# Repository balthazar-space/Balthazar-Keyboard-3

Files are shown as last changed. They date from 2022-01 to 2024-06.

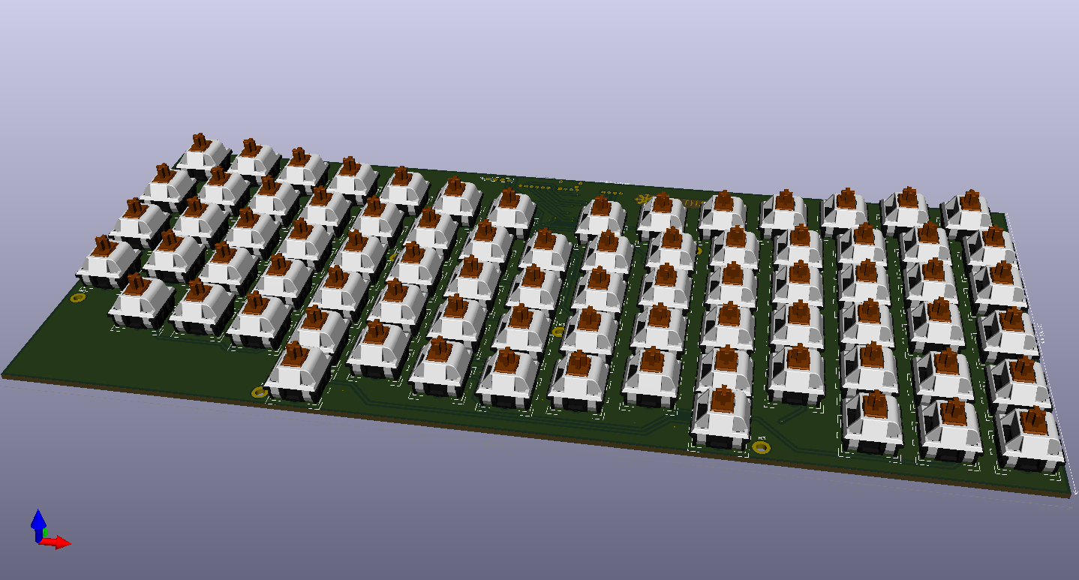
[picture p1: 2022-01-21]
images/BalthazarKeyboard3-keycaps02.png

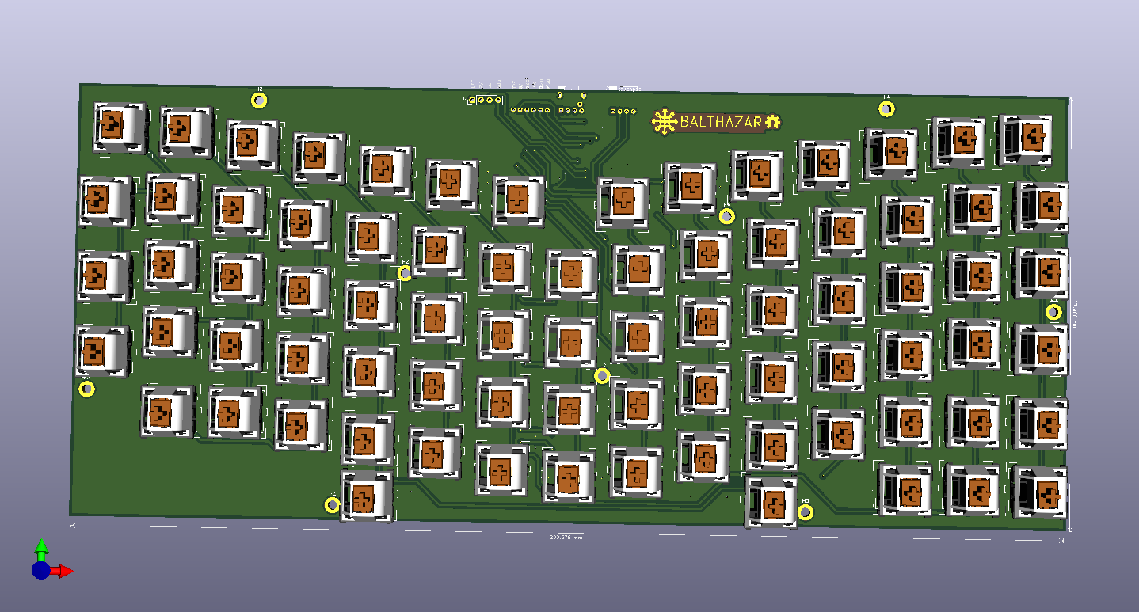
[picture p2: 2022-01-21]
images/BalthazarKeyboard3-keycaps01.png

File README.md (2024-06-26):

# Balthazar

Open-hardware laptop computer modules description and concept.

These are electronic schematic modules as presented at https://balthazar.space/wiki/Balthazar with the main aim for team access. See the [main repository](https://github.com/balthazar-space/balthazar) for other designs.

# Balthazar Keyboard 3

Balthazar keyboard with keycaps.

Computer Keyboard version 3 system built around an 8-bit Atmel ATmega 32u4 microcontroller. A normal ISO keyboard layout is used. The PCB design is for Cherry keycaps. Schematics layout and connections are a bit simplified over version 2.

An option is given for the onboard microcontroller to handle also the control for PSU board, the OLED module, bluetooth module and the ps/2 touchpad module. For this I2C, SPI and PS/2 serial connections are exposed - and are optional. The QMK code has not been updated with all these options yet. 

QMK code in QMK folder reflects the simplifications of this version - basically just the more straightforward selection of row pins of the microcontroller.

Keyboard pcb has dimensions predefined by the LCD's dimensions of 13.3 inch diagonal: 290mm width. The width is the most determining factor for the keys raster which is about 17mm – instead of the regular 19mm.

The keys have some ergonomic solution that gives some additional design touch. The keycaps here are positioned vertically which is not the best solution (keycaps orientation should follow the wave of the design...). 

KiCad 5.1.5 files are uploaded here as well as the drawings pictures and firmware code.

### OLED & boot sequence

A 128x32 SSD130 64x128 display connected via i2c is used.
When starting up, you are asked to enter a password. If it's not set up yet, a new one can be entered.
After successful authentication, a boot menu is presented.

**_beware:_** The password is saved plaintext in the microcontroller's EEPROM. It can be extracted with proper equipment and can easily be overwritten on the currently used ATmega32u4.

## License

All resources except the keyboard firmware - which is licensed with with GPLv3 or later - licensed under the CERN Open Hardware Licence CERN-OHL W V.2.0

Version 2.0 of the CERN-OHL introduces three variants of the licence – strongly (S) reciprocal, weakly (W) reciprocal and permissive (P) – which aim to address specific constraints caused by different collaboration models currently used in open-hardware projects. 

The first two variants mean that if any product is made using an open hardware design, the design of that product, including any improvements or modifications, should be made available under the same licence as that of the original product. Permissive licences do not impose this condition.

See the [LICENSE.md](./LICENSE.md) file for more information.

## Funding

This project is funded through the [NGI Zero Entrust Fund](https://nlnet.nl/entrust), a fund
established by [NLnet](https://nlnet.nl) with financial support from the European Commission's
[Next Generation Internet](https://ngi.eu) program. Learn more on the [NLnet project page](https://nlnet.nl/project/Balthazar-Casing/).

[NLNet foundation logo](https://nlnet.nl)
[NGI0 Entrust Logo](https://nlnet.nl/entrust)

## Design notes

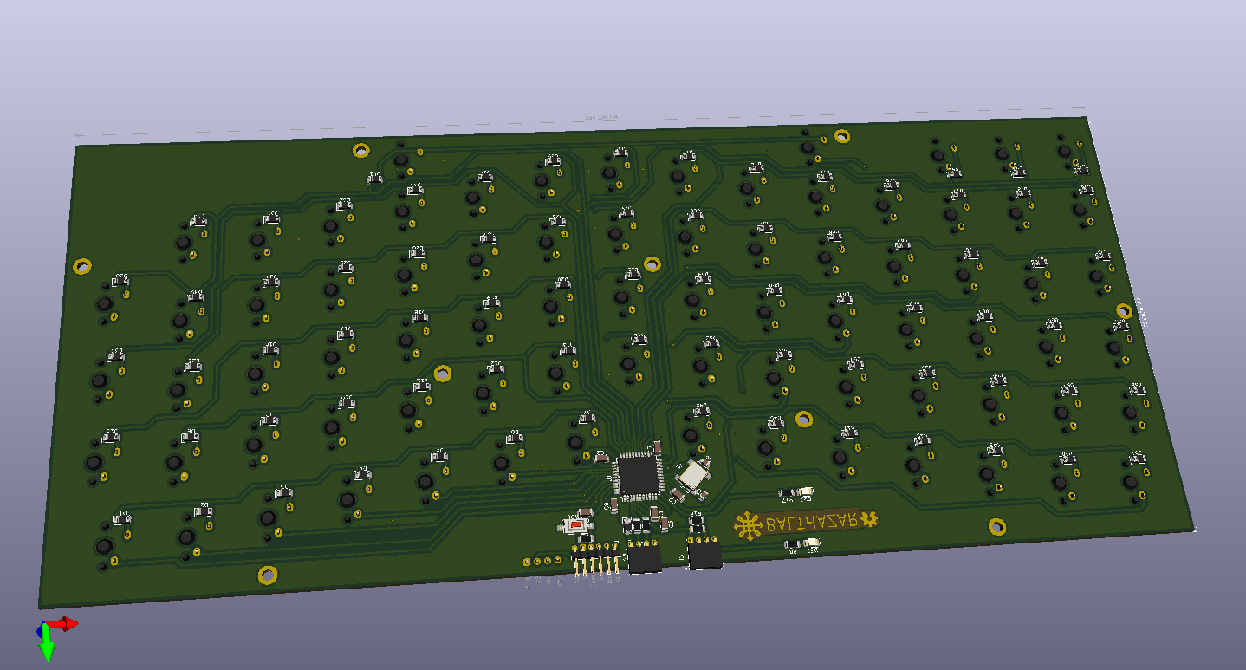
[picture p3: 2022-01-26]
images/BalthazarKeyboard3-keycaps05.png

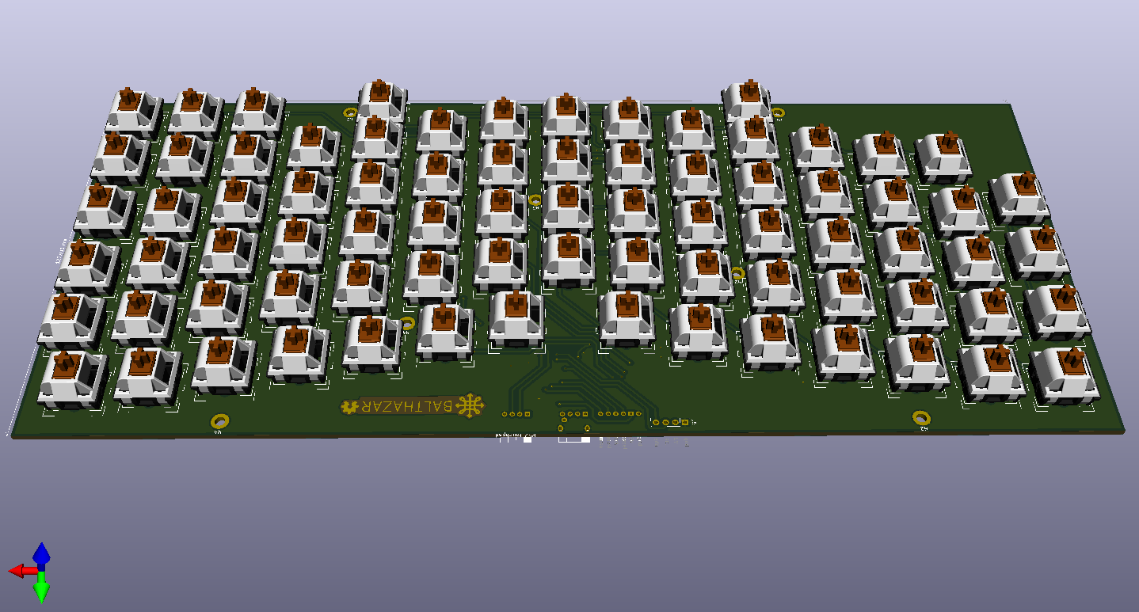
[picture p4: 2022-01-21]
images/BalthazarKeyboard3-keycaps04.png

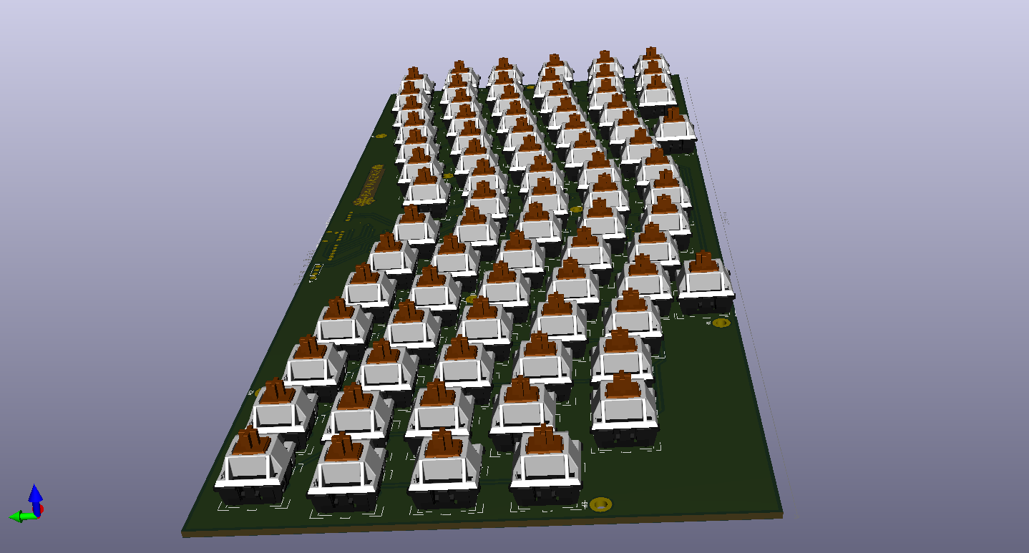
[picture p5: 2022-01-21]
images/BalthazarKeyboard3-keycaps03.png

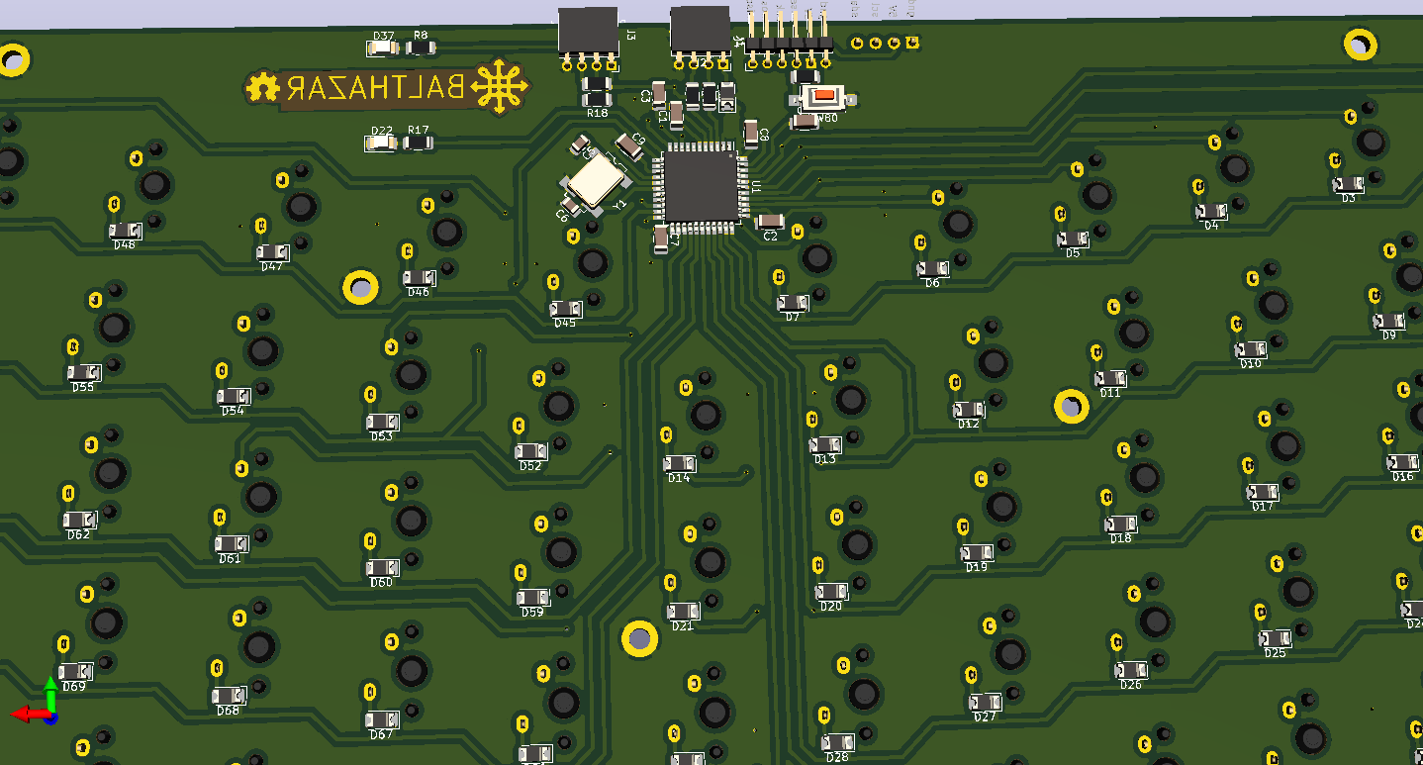
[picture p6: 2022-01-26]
images/BalthazarKeyboard3-keycaps06.png

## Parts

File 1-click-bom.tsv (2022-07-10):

References | Qty | Description | Manufacturer | MPN | Manufacturer | MPN | Manufacturer | MPN | Manufacturer | MPN | Manufacturer | MPN | Manufacturer | MPN | Digikey | Mouser | RS | Newark | Farnell | LCSC | JLC Assembly
C1 | 1 | Multilayer Ceramic Capacitors MLCC - SMD/SMT WCAP-CSGP 1uF 1206 10% 16V MLCC | Wurth Elektronik | 885012208036 | AVX | 885012208036 | AVX | TAJA105K035RNJ |  | TAJA105K035RNJ |  |  |  |  | 732-7692-6-ND | 581TAJA105K035R | 1360144 |  | 1135061
C2 | 1 | Multilayer Ceramic Capacitors MLCC - SMD/SMT 25 VDC 10uF X5R 1206 | KEMET | C1206C106M3PAC7210 |  | C1206C106M3PAC7210 |  |  |  |  |  |  |  |  |  | 80C1206C106M3PACLR |  |  | 3511493
C5, C6 | 2 | Multilayer Ceramic Capacitors MLCC - SMD/SMT 16V 22pF C0G 0805 5% | KYOCERA AVX | 885012007012 | Wurth Elektronik | 885012007012 |  |  |  |  |  |  |  |  | 732-7816-1-ND | 710885012007012 | 1814089 |  | 2812134
D1, D2, D3, D4, D5, D6, D7, D8, D9, D10, D11, D12, D13, D14, D15, D16, D17, D18, D19, D20, D21, D23, D24, D25, D26, D27, D28, D29, D30, D31, D32, D33, D34, D35, D36, D38, D39, D40, D41, D42, D43, D44, D45, D46, D47, D48, D49, D50, D51, D52, D53, D54, D55, D56, D57, D58, D59, D60, D61, D62, D63, D64, D65, D66, D67, D68, D69, D70, D71, D72, D73, D74, D75, D76, D77, D78, D79 | 77 | Diodes - General Purpose, Power, Switching 75V, 0.15A, Switching Diode & Array | Taiwan Semiconductor | TS4148 RXG |  | TS4148 RXG |  |  |  |  |  |  |  |  |  | 821TS4148RXG | 6526003 |  | 2708388
C3, C4, C7, C8, C9 | 5 | Multilayer Ceramic Capacitors MLCC - SMD/SMT 50V 0.1uF X7R 1206 20% | KEMET | C1206C104M5RACTU |  | C1206C104M5RACTU |  |  |  |  |  |  |  |  | 399-C1206C104M5RAC7800DKR-ND | 80C1206C104M5R | 2053277P |  | 2581103 |  | ,,,,,,,,,,,,,,,,,,,,,,,,,,,,,,,,,,,,,,,,,,,,,,,,,,,,,,,,,,,,,,,,,,,,,,,,,,,,
R7, R18, R19 | 3 | Thick Film Resistors - SMD 10 kOhms 250 mW 1206 5% | Vishay | RC1206JR-0710KL | Panasonic | CRCW120610K0FKEA | Yageo | ERJ-8ENF1002V | Yageo | RC1206FR-0710KL | Yageo | RC1206JR-0710KL |  | RC1206JR-0710KL | 311-10.0KFRCT-ND | 603RC1206FR0710KL | 1995772P |  | 9241000
R3, R4 | 2 | Thick Film Resistors - SMD 22ohms 1% 100ppm | Vishay Dale | RCC120622R0FKEA |  | RCC120622R0FKEA |  |  |  |  |  |  |  |  | 541-RCC120622R0FKEADKR-ND | 71RCC120622R0FKEA |  |  | 3755550
R8, R17 | 2 | Thick Film Resistors - SMD 200 Ohms 250 mW 1206 1% | Yageo | RC1206FR-07200RL |  | RC1206FR-07200RL |  |  |  |  |  |  |  |  | 311-200FRDKR-ND | 603RC1206FR07200RL |  |  | 3496175
L1 | 1 | Fixed Inductors 1.5uH 10% | Cooper Bussmann | ILSB1206ER1R5K | Vishay Dale | MFBW1V3216-500-R | Vishay Dale | ILSB1206ER1R5K | Cooper Bussmann | ILSB1206ER1R5K |  | MFBW1V3216-500-R |  |  | ILSB1206ER1R5K-ND | 704MFBW1V3216500R
U1 | 1 | 8-bit Microcontrollers - MCU USB 32K Flash 16 MHz | Microchip | ATMEGA32U4-AUR |  | ATMEGA32U4-AUR |  |  |  |  |  |  |  |  | ATMEGA32U4-AURDKR-ND | 556ATMEGA32U4AUR | 1772992P |  | 2443182RL
Y1 | 1 | Standard Clock Oscillators SG-8018CB 16.0000M-TJHPA3: MHZ OSC 1.8V~3.3V +/-50PPM -40~105C O/E 250TR | Epson | SG-8018CB 16.0000M-TJHPA3 |  | SG-8018CB 16.0000M-TJHPA3 |  |  |  |  |  |  |  |  |  | 732CB16MTJHPA3
D22, D37 | 2 | Standard LEDs - SMD Green | Stanley Electric | RPG1102W-660-TR |  | RPG1102W-660-TR |  |  |  |  |  |  |  |  | 404-1232-1-ND | 327RPG1102W660TR
SW1-SW79 | 78 | Pushbutton Switches Silver stem, RGB | Cherry | MX1A-51NA |  | MX1A-51NA |  | MX1A-11NW |  |  |  |  |  |  | MX1A-51NA-ND | 540MX1A11NW
SW80 | 1 | Tactile Switches SPST 0.05A 12V 250gf | C&K Components | RS282G05A3SMRT |  | RS282G05A3SMRT |  |  |  |  |  |  |  |  | CKN10384CT-ND | 611RS282G05A3SMRT | 1769434 |  | 3263270
J2 | 1 | USB Connectors Micro B Skt, Top Mount-SMT | Global Connector Technology | USB3505-30-A |  | USB3505-30-A |  |  |  |  |  |  |  |  | 2073-USB3505-30-ATR-ND | 640USB350530A
KEYCAPS | 78 | KEYCAPS CHERRY MX |  | 474-PRT-15305 |  | PRT-15305 |  |  |  |  |  |  |  |  |  | 474PRT15305
J1, J3 | 2 | PinSocket_1x04_P2.00mm_Horizontal |  | SQT-104-01-F-S-RA |  |  |  |  |  |  |  |  |  |  |  | 200SQT10401FSRA
J4 | 1 | PinHeader_1x06_P2.00mm_Horizontal |  | 35363-0660 |  |  |  |  |  |  |  |  |  |  |  | 538353630660
J5 | 1 | PinHeader_1x04_P2.54mm_Vertical |  | M20-9990446 |  |  |  |  |  |  |  |  |  |  |  | 855M209990446

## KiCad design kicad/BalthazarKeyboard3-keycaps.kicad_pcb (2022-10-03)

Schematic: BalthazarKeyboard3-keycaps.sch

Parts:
C1: 1uF; C_1206_3216Metric
C2: 10uF; C_1206_3216Metric
C3, C4, C7, C8, C9: 0.1uF; C_1206_3216Metric
C5, C6: 22pF; C_0805_2012Metric
D1, D2, D3, D4, D5, D6, D7, D8, D9, D10, D11, D12, D13, D14, D15, D16, D17, D18, D19, D20, D21, D23, D24, D25, D26, D27, D28, D29, D30, D31, D32, D33, D34, D35, D36, D38, D39, D40, D41, D42, D43, D44, D45, D46, D47, D48, D49, D50, D51, D52, D53, D54, D55, D56, D57, D58, D59, D60, D61, D62, D63, D64, D65, D66, D67, D68, D69, D70, D71, D72, D73, D74, D75, D76, D77, D78, D79: D; D_1206_3216Metric
D22, D37: LED_Small; LED_1206_3216Metric
H1, H2, H3, H4: MountingHole_Pad; MountingHole_2.7mm_M2.5_DIN965_Pad
J1: USB; PinSocket_1x04_P2.00mm_Horizontal
J2: USB_B_Micro; USB_Micro-B_Molex-Balthazar
J3: PS2 touchpad; PinSocket_1x04_P2.00mm_Horizontal
J4: ISP; PinHeader_1x06_P2.00mm_Horizontal
J5: I2C; PinHeader_1x04_P2.54mm_Vertical
L1: L_Core_Ferrite_Small; D_1206_3216Metric
R3, R4: 22; R_1206_3216Metric
R7, R18, R19: 10K; R_1206_3216Metric
R8, R17: 200; R_1206_3216Metric
SW1: ESC; CherryMX_RGB_SpeedSilver
SW2: F1; CherryMX_RGB_SpeedSilver
SW3: F2; CherryMX_RGB_SpeedSilver
SW4: F3; CherryMX_RGB_SpeedSilver
SW5: F4; CherryMX_RGB_SpeedSilver
SW6: F5; CherryMX_RGB_SpeedSilver
SW7: F6; CherryMX_RGB_SpeedSilver
SW8: GRAVE; CherryMX_RGB_SpeedSilver
SW9: 1; CherryMX_RGB_SpeedSilver
SW10: 2; CherryMX_RGB_SpeedSilver
SW11: 3; CherryMX_RGB_SpeedSilver
SW12: 4; CherryMX_RGB_SpeedSilver
SW13: 5; CherryMX_RGB_SpeedSilver
SW14: 6; CherryMX_RGB_SpeedSilver
SW15: TAB; CherryMX_RGB_SpeedSilver
SW16: Q; CherryMX_RGB_SpeedSilver
SW17: W; CherryMX_RGB_SpeedSilver
SW18: E; CherryMX_RGB_SpeedSilver
SW19: R; CherryMX_RGB_SpeedSilver
SW20: T; CherryMX_RGB_SpeedSilver
SW21: Y; CherryMX_RGB_SpeedSilver
SW22: CAPS; CherryMX_RGB_SpeedSilver
SW23: A; CherryMX_RGB_SpeedSilver
SW24: S; CherryMX_RGB_SpeedSilver
SW25: D; CherryMX_RGB_SpeedSilver
SW26: F; CherryMX_RGB_SpeedSilver
SW27: G; CherryMX_RGB_SpeedSilver
SW28: H; CherryMX_RGB_SpeedSilver
SW29: SHIFT; CherryMX_RGB_SpeedSilver
SW30: NUBS; CherryMX_RGB_SpeedSilver
SW31: Z; CherryMX_RGB_SpeedSilver
SW32: X; CherryMX_RGB_SpeedSilver
SW33: C; CherryMX_RGB_SpeedSilver
SW34: V; CherryMX_RGB_SpeedSilver
SW35: B; CherryMX_RGB_SpeedSilver
SW36: CTRL; CherryMX_RGB_SpeedSilver
SW37: ALT; CherryMX_RGB_SpeedSilver
SW38: GUI; CherryMX_RGB_SpeedSilver
SW39, SW40: SPACE; CherryMX_RGB_SpeedSilver
SW42: LEFT; CherryMX_RGB_SpeedSilver
SW43: DOWN; CherryMX_RGB_SpeedSilver
SW44: RIGHT; CherryMX_RGB_SpeedSilver
SW45: F7; CherryMX_RGB_SpeedSilver
SW46: F8; CherryMX_RGB_SpeedSilver
SW47: F9; CherryMX_RGB_SpeedSilver
SW48: F10; CherryMX_RGB_SpeedSilver
SW49: F11; CherryMX_RGB_SpeedSilver
SW50: F12; CherryMX_RGB_SpeedSilver
SW51: PRTSCR; CherryMX_RGB_SpeedSilver
SW52: 7; CherryMX_RGB_SpeedSilver
SW53: 8; CherryMX_RGB_SpeedSilver
SW54: 9; CherryMX_RGB_SpeedSilver
SW55: 0; CherryMX_RGB_SpeedSilver
SW56: MINUS; CherryMX_RGB_SpeedSilver
SW57: EQUAL; CherryMX_RGB_SpeedSilver
SW58: DELETE; CherryMX_RGB_SpeedSilver
SW59: U; CherryMX_RGB_SpeedSilver
SW60: I; CherryMX_RGB_SpeedSilver
SW61: O; CherryMX_RGB_SpeedSilver
SW62: P; CherryMX_RGB_SpeedSilver
SW63: LBRC; CherryMX_RGB_SpeedSilver
SW64: RBRC; CherryMX_RGB_SpeedSilver
SW65: BACKSPACE; CherryMX_RGB_SpeedSilver
SW66: J; CherryMX_RGB_SpeedSilver
SW67: K; CherryMX_RGB_SpeedSilver
SW68: L; CherryMX_RGB_SpeedSilver
SW69: SCLN; CherryMX_RGB_SpeedSilver
SW70: QUOTE; CherryMX_RGB_SpeedSilver
SW71: NUHS; CherryMX_RGB_SpeedSilver
SW72: ENTER; CherryMX_RGB_SpeedSilver
SW73: N; CherryMX_RGB_SpeedSilver
SW74: M; CherryMX_RGB_SpeedSilver
SW75: COMMA; CherryMX_RGB_SpeedSilver
SW76: DOT; CherryMX_RGB_SpeedSilver
SW77: SLASH; CherryMX_RGB_SpeedSilver
SW78: UP; CherryMX_RGB_SpeedSilver
SW79: ALTGR; CherryMX_RGB_SpeedSilver
SW80: SW_Push; SW_SPST_CK_RS282G05A3
U1: ATmega32U4_Balthazar; TQFP-44_10x10mm_P0.8mm
U3: Arduino_ProMicro
Y1: Crystal_16M; Crystal_SMD_SeikoEpson_MC306-4Pin_8.0x3.2mm_HandSoldering

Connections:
GND: C1.2, C2.1, C3.1, C4.2, C5.2, C6.2, C7.1, C8.1, C9.1, D22.1 (K), D37.1 (K), H1.1, H2.1, H3.1, H4.1, J1.4, J2.5 (GND), J2.6 (Shield), J3.4, J4.6, J5.1, SW80.1, U1.5 (UGND), U1.15 (GND), U1.23 (GND), U1.35 (GND), U1.43 (GND), Y1.2, Y1.4; also elsewhere on the board
unnamed: C1.1, U1.6 (UCAP)
unnamed: C4.1, U1.42 (AREF)
unnamed: C5.1, U1.16 (XTAL2), Y1.1
unnamed: C6.1, U1.17 (XTAL1), Y1.3
unnamed: D1.2 (A), SW1.2
unnamed: D2.2 (A), SW2.2
unnamed: D3.2 (A), SW3.2
unnamed: D4.2 (A), SW4.2
unnamed: D5.2 (A), SW5.2
unnamed: D6.2 (A), SW6.2
unnamed: D7.2 (A), SW7.2
unnamed: D8.2 (A), SW8.2
unnamed: D9.2 (A), SW9.2
unnamed: D10.2 (A), SW10.2
unnamed: D11.2 (A), SW11.2
unnamed: D12.2 (A), SW12.2
unnamed: D13.2 (A), SW13.2
unnamed: D14.2 (A), SW14.2
unnamed: D15.2 (A), SW15.2
unnamed: D16.2 (A), SW16.2
unnamed: D17.2 (A), SW17.2
unnamed: D18.2 (A), SW18.2
unnamed: D19.2 (A), SW19.2
unnamed: D20.2 (A), SW20.2
unnamed: D21.2 (A), SW21.2
unnamed: D22.2 (A), R17.1
unnamed: D23.2 (A), SW22.2
unnamed: D24.2 (A), SW23.2
unnamed: D25.2 (A), SW24.2
unnamed: D26.2 (A), SW25.2
unnamed: D27.2 (A), SW26.2
unnamed: D28.2 (A), SW27.2
unnamed: D29.2 (A), SW28.2
unnamed: D30.2 (A), SW29.2
unnamed: D31.2 (A), SW30.2
unnamed: D32.2 (A), SW31.2
unnamed: D33.2 (A), SW32.2
unnamed: D34.2 (A), SW33.2
unnamed: D35.2 (A), SW34.2
unnamed: D36.2 (A), SW35.2
unnamed: D37.2 (A), R8.1
unnamed: D38.2 (A), SW36.2
unnamed: D39.2 (A), SW37.2
unnamed: D40.2 (A), SW38.2
unnamed: D41.2 (A), SW39.2, SW40.2
unnamed: D42.2 (A), SW42.2
unnamed: D43.2 (A), SW43.2
unnamed: D44.2 (A), SW44.2
unnamed: D45.2 (A), SW45.2
unnamed: D46.2 (A), SW46.2
unnamed: D47.2 (A), SW47.2
unnamed: D48.2 (A), SW48.2
unnamed: D49.2 (A), SW49.2
unnamed: D50.2 (A), SW50.2
unnamed: D51.2 (A), SW51.2
unnamed: D52.2 (A), SW52.2
unnamed: D53.2 (A), SW53.2
unnamed: D54.2 (A), SW54.2
unnamed: D55.2 (A), SW55.2
unnamed: D56.2 (A), SW56.2
unnamed: D57.2 (A), SW57.2
unnamed: D58.2 (A), SW58.2
unnamed: D59.2 (A), SW59.2
unnamed: D60.2 (A), SW60.2
unnamed: D61.2 (A), SW61.2
unnamed: D62.2 (A), SW62.2
unnamed: D63.2 (A), SW63.2
unnamed: D64.2 (A), SW64.2
unnamed: D65.2 (A), SW65.2
unnamed: D66.2 (A), SW66.2
unnamed: D67.2 (A), SW67.2
unnamed: D68.2 (A), SW68.2
unnamed: D69.2 (A), SW69.2
unnamed: D70.2 (A), SW70.2
unnamed: D71.2 (A), SW71.2
unnamed: D72.2 (A), SW72.2
unnamed: D73.2 (A), SW73.2
unnamed: D74.2 (A), SW74.2
unnamed: D75.2 (A), SW75.2
unnamed: D76.2 (A), SW76.2
unnamed: D77.2 (A), SW77.2
unnamed: D78.2 (A), SW78.2
unnamed: D79.2 (A), SW79.2
unnamed: J1.1, J2.1 (VBUS), L1.2
unnamed: J1.2, J2.2 (D-), R3.1
unnamed: J1.3, J2.3 (D+), R4.1
unnamed: J4.1, U1.11 (PB3)
unnamed: J4.2, U1.10 (PB2)
unnamed: J4.3, U1.9 (PB1)
unnamed: J5.3, U1.18 (PD0)
unnamed: J5.4, U1.19 (PD1)
unnamed: R3.2, U1.3 (D-)
unnamed: R4.2, U1.4 (D+)
unnamed: R17.2, U1.8 (PB0)
PS2clock: J3.2, R18.2, U1.22 (PD5)
PS2data: J3.3, R19.2, U1.20 (PD2)
RST: J4.4, R7.2, SW80.2, U1.13 (~RESET)
Vcc: C2.2, C3.2, C7.2, C8.2, C9.2, J3.1, J4.5, J5.2, L1.1, R7.1, R8.2, R18.1, R19.1, U1.2 (UVCC), U1.7 (VBUS), U1.14 (VCC), U1.24 (AVCC), U1.34 (Vcc), U1.44 (Vcc)
col1: D1.1 (K), D2.1 (K), D3.1 (K), D4.1 (K), D5.1 (K), D6.1 (K), D7.1 (K), U1.33 (~HWB~/PE2)
col2: D8.1 (K), D9.1 (K), D10.1 (K), D11.1 (K), D12.1 (K), D13.1 (K), D14.1 (K), U1.32 (PC7)
col3: D15.1 (K), D16.1 (K), D17.1 (K), D18.1 (K), D19.1 (K), D20.1 (K), D21.1 (K), U1.31 (PC6)
col4: D23.1 (K), D24.1 (K), D25.1 (K), D26.1 (K), D27.1 (K), D28.1 (K), D29.1 (K), U1.30 (PB6)
col5: D30.1 (K), D31.1 (K), D32.1 (K), D33.1 (K), D34.1 (K), D35.1 (K), D36.1 (K), U1.29 (PB5)
col6: D38.1 (K), D39.1 (K), D40.1 (K), D41.1 (K), D42.1 (K), D43.1 (K), D44.1 (K), U1.28 (PB4)
col7: D73.1 (K), D74.1 (K), D75.1 (K), D76.1 (K), D77.1 (K), D78.1 (K), D79.1 (K), U1.27 (PD7)
col8: D66.1 (K), D67.1 (K), D68.1 (K), D69.1 (K), D70.1 (K), D71.1 (K), D72.1 (K), U1.26 (PD6)
col9: D59.1 (K), D60.1 (K), D61.1 (K), D62.1 (K), D63.1 (K), D64.1 (K), D65.1 (K), U1.25 (PD4)
col10: D52.1 (K), D53.1 (K), D54.1 (K), D55.1 (K), D56.1 (K), D57.1 (K), D58.1 (K), U1.12 (PB7)
col11: D45.1 (K), D46.1 (K), D47.1 (K), D48.1 (K), D49.1 (K), D50.1 (K), D51.1 (K), U1.21 (PD3)
row1: SW1.1, SW8.1, SW15.1, SW22.1, SW29.1, SW36.1, SW45.1, SW52.1, SW59.1, SW66.1, SW73.1, U1.41 (PF0)
row2: SW2.1, SW9.1, SW16.1, SW23.1, SW30.1, SW37.1, SW46.1, SW53.1, SW60.1, SW67.1, SW74.1, U1.40 (PF1)
row3: SW3.1, SW10.1, SW17.1, SW24.1, SW31.1, SW38.1, SW47.1, SW54.1, SW61.1, SW68.1, SW75.1, U1.39 (PF4)
row4: SW4.1, SW11.1, SW18.1, SW25.1, SW32.1, SW39.1, SW40.1, SW48.1, SW55.1, SW62.1, SW69.1, SW76.1, U1.38 (PF5)
row5: SW5.1, SW12.1, SW19.1, SW26.1, SW33.1, SW42.1, SW49.1, SW56.1, SW63.1, SW70.1, SW77.1, U1.37 (PF6)
row6: SW6.1, SW13.1, SW20.1, SW27.1, SW34.1, SW43.1, SW50.1, SW57.1, SW64.1, SW71.1, SW78.1, U1.36 (PF7)
row7: SW7.1, SW14.1, SW21.1, SW28.1, SW35.1, SW44.1, SW51.1, SW58.1, SW65.1, SW72.1, SW79.1, U1.1 (PE6)

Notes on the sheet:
ATMEGA32U4 AU DFU botloader installed - /HWB low during power up: use USB bootloader microcontroller acts as I2C psu and PS/2 touchpad controller 25 pins available 18 keys matrix: 11 x 7 = 77 2 pins I2C sda and scl - optional PSU control 3 pins SPI (sclk, miso, mosi) are shared as int, otg - option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
Balthazar Computer Keyboard Atmel 32U4 driver version 7 x 11 matrix = 77 keys
Dimensions defined by display 1920 x 1080 = 1.78 B133XW04 outer dimensions: 307.6 × 183.1 ×5.07 mm 13.3 inch -> 16:9 -> W x H = 295 x 166 mm <- OK 12.5 inch -> 16:9 -> W x H = 277 x 156 mm d = 374.44 mm => 13.7inch - available for touchpad = 47mm
Synptics touchpad module dimensions: Synaptics TM278 = 39 x 66 mm Synaptics TM42PDF1351 = 45 x 65 mm
The regular distance between two keys on a mechanical keyboard equals 0.75 inch (19.05 mm). This value is defined as 1U. This keyboard has 5 different keycap sizes: 1U, 1.25U, 1.5U, 1.75U and 2,25U.
3/2020
Balthazar Computer Keyboard
Pro micro bootloader pin definitions PB0: SS or RX LED = 17 PB1: SCK = 15 PB2: MOSI = 16 PB3: MISO = 14 PB7: nc PC7: nc PD5: TX LED = 30 PD6: nc PF0, PF1: nc
rows are sending cols are receiving row7: (PE6) A10 = D7 row6: (PF7) A0 = D18 row5: (PF6) A1 = D19 row4: (PF5) A2 = D20 row3: (PF4) A3 = D21 row2: (PF1) A4 = D22 row1: (PF0) A5 = D23 col1: D13 (PC7) col2: D5 (PC6) col3: D10 (PB6) = A13 col4: D9 (PB5) = A12 col5: D8 (PB4) = A11 col6: D12 (PD6) = A9 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
use PSU_I2C bus as SPI programming port (gnd, sck, mosi, miso, cc, reset, vcc)
HWB – Port E, Bit 2 HWB allows to execute the bootloader section after reset when tied to ground during external reset pulse (active only when the HWBE fuse is enabled).
LCD: 195 x 305 mm A4: 210 x 297 mm
UCAP - USB Pads Internal Regulator Output supply voltage 3V3. Should be connected to an external capacitor (1μF).
AREF analog reference pin (input) for the A/D Converter
PD5 - clock PD2 - data
USART (best) on ATMega32u4: use PD5 for clock and PD2 for data (if one unavailable - use the interrupt version)
sck
mosi
miso
rst
USB VBUS monitor input
If the ADC is not used, AVCC should be connected to VCC
gnd
Vcc
otg
int
PCINT3
PCINT2
PCINT1
PCINT0
PCINT4
scl
sda
ps/2 data rxd1
txd1
ps/2 clock
Ucap: USB driver regulator inside ATmega32U4 - needs 1uF capacitor for filtering - can draw additionally 50mA for powering external circuits or devices
Check the resonator Caps value: with MQ it is 12pF XTAL1 in (or XOSC in) XTAL2 out External Clock means XOSC
3-3.6V
TX yellow led on PB3 PD5/PS2clock is green led

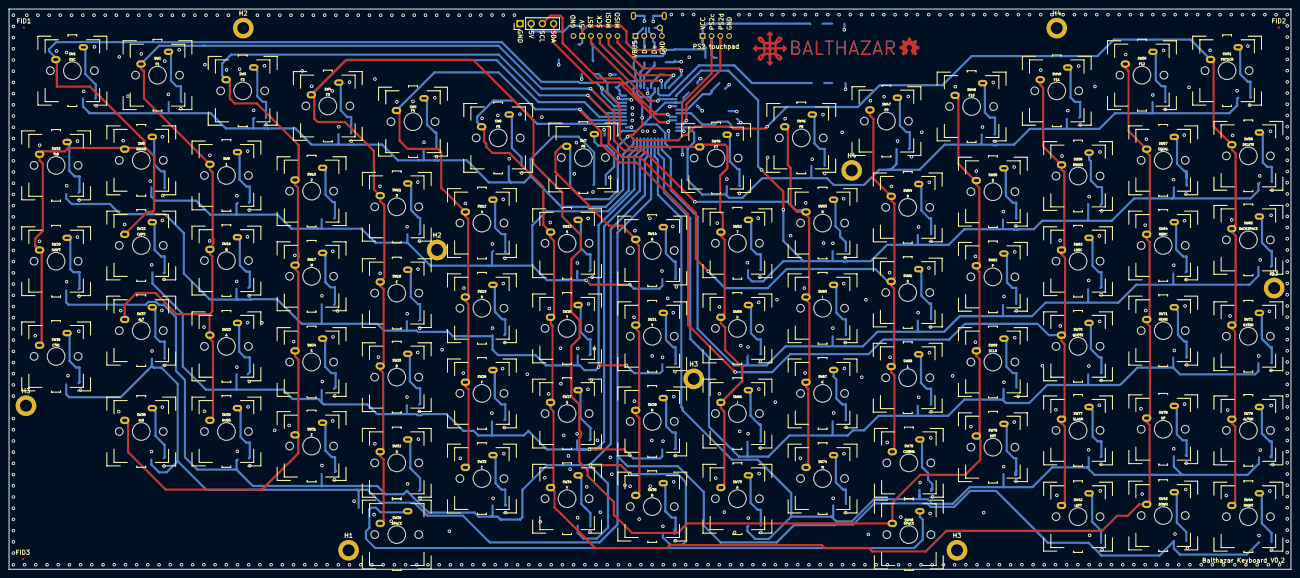
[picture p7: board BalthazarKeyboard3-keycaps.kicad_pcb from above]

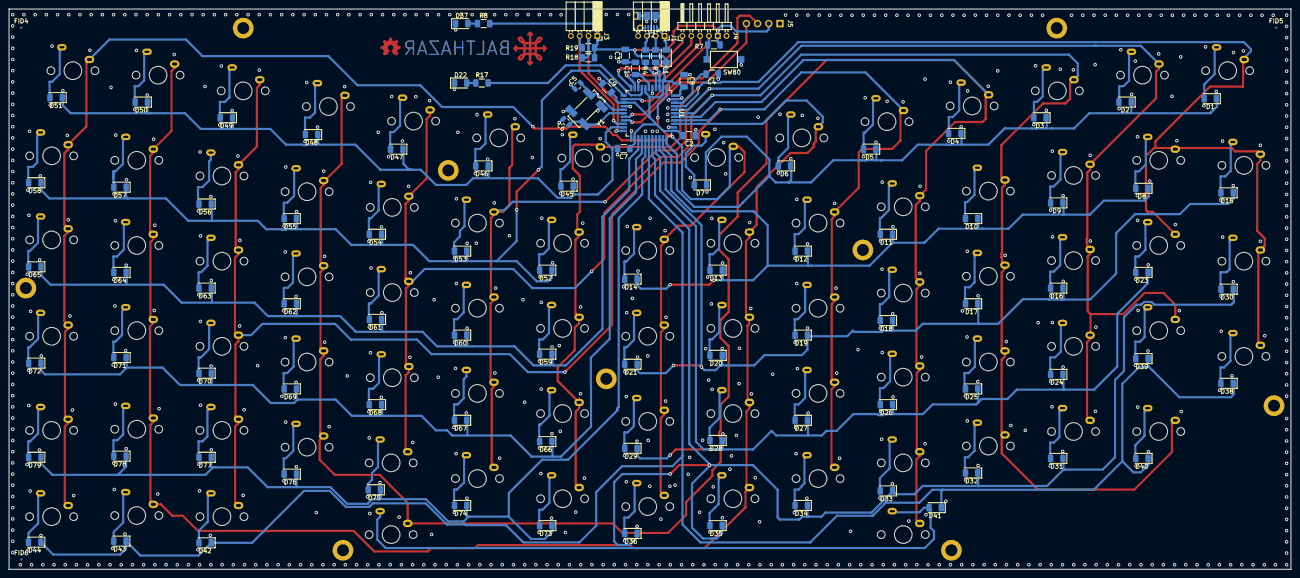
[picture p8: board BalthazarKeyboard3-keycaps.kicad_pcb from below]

Board: 4 copper layers, 290.6 x 127.0 mm, 197 parts (106 on the bottom side), 117 nets.

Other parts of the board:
FID1, FID2, FID3, FID4, FID5, FID6: Fiducial; Fiducial_0.5mm_Mask1mm
H2#2, H3#2, H3#3, H3#4, H4#2: MountingHole_Pad; MountingHole_2.7mm_M2.5_DIN965_Pad

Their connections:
GND: H2#2.1, H3#2.1, H3#3.1, H3#4.1, H4#2.1; also elsewhere on the board

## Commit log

2022-01-21 Add files via upload
    KiCAD 5 files for a version of Balthazar keyboard PCB with keycaps. Also a little bit simplified usage of microcontroller pins. This is reflected in QMK scripts - will be added soon.
    [BalthazarKeyboard3-keycaps.kicad_pcb, BalthazarKeyboard3-keycaps.sch]
2022-06-08 Adding interactive BOM
2022-06-28 Sorting files
    [BalthazarKeyboard3-keycaps-B_Cu.gbl, BalthazarKeyboard3-keycaps-B_Mask.gbs, BalthazarKeyboard3-keycaps-B_Paste.gbp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]
2022-06-28 Moving backups to kicad directory
2022-06-28 Adding initial 1-click bom
    [1-click-bom.tsv]
2022-07-10 Parts update
    [1-click-bom.tsv]
2022-10-03 Rotating all keys, rerouting PCB - fix #4
2022-10-03 Adding 2 leyer production files
    [BalthazarKeyboard3-keycaps-B_Cu.gbl, BalthazarKeyboard3-keycaps-B_Mask.gbs, BalthazarKeyboard3-keycaps-B_Paste.gbp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]
2022-10-03 Switching board to 4 layers
    [BalthazarKeyboard3-keycaps.kicad_pcb]
2022-10-03 Adding fidutials, adding pin descriptions
    [BalthazarKeyboard3-keycaps.kicad_pcb]
2022-10-03 Adding 4-layer production files
    [BalthazarKeyboard3-keycaps-B_Cu.gbl, BalthazarKeyboard3-keycaps-B_Mask.gbs, BalthazarKeyboard3-keycaps-B_Paste.gbp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]
